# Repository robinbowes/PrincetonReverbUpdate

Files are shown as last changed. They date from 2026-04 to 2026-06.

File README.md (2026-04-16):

# Yet another modded Princeton Reverb

I started off with a Modulus Amplification Princetown Reverb kit. That should have been it. But I wanted to do some of the mods people do, as well as incorporate some of the things Merlin Blencowe suggests in his books.

Initially, I thought I could get away with altering the supplied turret board. Alas, that was just taking up too much thinking time. It was far easier to just draw up a PCB.

The current PCB

Things I've done:

- moved the reverb to its own node
- moved the LFO to its own spur
- used an LED to bias the LFO
- added a large stopper to the PI grid
- reduced the PI coupling caps going to the 6V6s (I could reduce further, but we'll see)
- adopted a multi-star grounding scheme using ground planes for each node, that daisy chain from the reservoir cap to the input
- a single earth <-> signal ground connection near the input
- tried to make the off-board connections short
- it's all on one board! No need for a bias board.

## Things that could do with improving

Should anyone want to take this and make it better, I'd add another mounting hole somewhere in the middle. 

## Licence

This project is licensed under **Creative Commons Attribution-NonCommercial-ShareAlike 4.0 International (CC BY-NC-SA 4.0)**.

© 2026 Tristan Collins

### You are free to:
- **Use and study** the design for personal, educational, or research purposes
- **Adapt** — remix, modify, or build upon it
- **Share** — redistribute in any medium or format

### Under these conditions:
- **Attribution** — credit the original, link to the licence, note any changes
- **NonCommercial** — may not be used for commercial purposes without permission
- **ShareAlike** — adaptations must be released under the same licence

### Commercial use
If you want to manufacture or sell PCBs, kits, or assemblies based on this design, you need a commercial licence. Get in touch: **hard.zoo4108@fastmail.com**



Full licence text: [LICENSE](./LICENSE)

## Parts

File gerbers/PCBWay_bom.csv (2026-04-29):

Designator | Quantity | Value | Footprint | Package | MPN | DNP | Mount_Type | Description | Sim.Device | Sim.Pins | Sim.Pin
C1, C12, C2, C24, C29, C7, C9 | 7 | 22u 50V | CP_Radial_D5.0mm_P2.00mm |  |  |  | tht | [C7,C9]Unpolarized capacitor; [C24,C29]Polarized capacitor
C10 | 1 | 10p 500V | C_Disc_D10.5mm_W5.0mm_P7.50mm_TC |  |  |  | tht | Unpolarized capacitor
C11 | 1 | 3.3n 630V | C_Rect_L16.5mm_W6.0mm_P15.00mm_MKT_TC |  |  |  | tht | Unpolarized capacitor
C13 | 1 | 10n 630V | C_Rect_L11.0mm_W5.1mm_P10.00mm_MKT_TC |  |  |  | tht | Unpolarized capacitor
C14, C19, C8 | 3 | 22n 630V | C_Axial_L17.0mm_D6.5mm_P20.00mm_Horizontal_TC |  |  |  | tht | Unpolarized capacitor
C15, C17 | 2 | 22n 630V | C_Rect_L11.0mm_W5.1mm_P10.00mm_MKT_TC |  |  |  | tht | Unpolarized capacitor
C18, C23, C25 | 3 | 22u 450V | CP_Radial_D12.5mm_P5.00mm |  |  |  | tht | Polarized capacitor
C20, C21 | 2 | 47n 630V | C_Axial_L19.0mm_D7.5mm_P25.00mm_Horizontal_TC |  |  |  | tht | Unpolarized capacitor
C22, C4 | 2 | 100n 630V | C_Axial_L22.0mm_D10.5mm_P27.50mm_Horizontal_TC |  |  |  | tht | Unpolarized capacitor
C27 | 1 | 100p | C_Disc_D10.5mm_W5.0mm_P7.50mm_TC |  |  |  | tht | Unpolarized capacitor
C3 | 1 | 250p 500V | C_Disc_D10.5mm_W5.0mm_P7.50mm_TC |  |  |  | tht | Unpolarized capacitor
C5 | 1 | 47n 630V | C_Axial_L17.0mm_D6.5mm_P20.00mm_Horizontal_TC |  |  |  | tht | Unpolarized capacitor
C6 | 1 | 470p 500V | C_Disc_D7.5mm_W5.0mm_P7.50mm_TC |  |  |  | tht | Unpolarized capacitor
D1 | 1 | UF4007 | D_DO-41_SOD81_P7.62mm_Horizontal |  |  |  | tht | Diode | D | 1=K 2=A
D2 | 1 | Red | LED_D5.0mm |  |  |  | tht | Light emitting diode, small symbol |  |  | 1=K 2=A
R10 | 1 | 6.8k | R_Axial_DIN0414_L11.9mm_D4.5mm_P15.24mm_Horizontal_TC |  |  |  | tht | Resistor
R11, R14, R18, R4, R5 | 5 | 1.5k | R_Axial_DIN0414_L11.9mm_D4.5mm_P15.24mm_Horizontal_TC |  |  |  | tht | Resistor
R12, R29, R33, R34 | 4 | 220k | R_Axial_DIN0414_L11.9mm_D4.5mm_P15.24mm_Horizontal_TC |  |  |  | tht | Resistor
R13, R16, R20, R39, R7, R8 | 6 | 100k | R_Axial_DIN0414_L11.9mm_D4.5mm_P15.24mm_Horizontal_TC |  |  |  | tht | Resistor
R15 | 1 | 3.3M | R_Axial_DIN0414_L11.9mm_D4.5mm_P15.24mm_Horizontal_TC |  |  |  | tht | Resistor
R17 | 1 | 470k | R_Axial_DIN0414_L11.9mm_D4.5mm_P15.24mm_Horizontal_TC |  |  |  | tht | Resistor
R19 | 1 | 47r | R_Axial_DIN0414_L11.9mm_D4.5mm_P15.24mm_Horizontal_TC |  |  |  | tht | Resistor
R21, R23, R24, R31, R6 | 5 | 1Meg | R_Axial_DIN0414_L11.9mm_D4.5mm_P15.24mm_Horizontal_TC |  |  |  | tht | Resistor
R22 | 1 | 2.7k | R_Axial_DIN0414_L11.9mm_D4.5mm_P15.24mm_Horizontal_TC |  |  |  | tht | Resistor
R26 | 1 | 1k | R_Axial_DIN0414_L11.9mm_D4.5mm_P15.24mm_Horizontal_TC |  |  |  | tht | Resistor
R27, R30 | 2 | 56k | R_Axial_DIN0414_L11.9mm_D4.5mm_P15.24mm_Horizontal_TC |  |  |  | tht | Resistor
R28 | 1 | 10k 1W | R_Axial_DIN0617_L17.0mm_D6.0mm_P20.32mm_Horizontal_TC |  |  |  | tht | Resistor
R35 | 1 | 10k | R_Axial_DIN0414_L11.9mm_D4.5mm_P15.24mm_Horizontal_TC |  |  |  | tht | Resistor
R37 | 1 | 100k 1W | R_Axial_DIN0414_L11.9mm_D4.5mm_P15.24mm_Horizontal_TC |  |  |  | tht | Resistor
R40, R41, R9 | 3 | 10k 3W | R_Axial_DIN0617_L17.0mm_D6.0mm_P20.32mm_Horizontal_TC |  |  |  | tht | Resistor
R42 | 1 | 1k 3W | R_Axial_DIN0617_L17.0mm_D6.0mm_P20.32mm_Horizontal_TC |  |  |  | tht | Resistor
R46 | 1 | 220k 3W | R_Axial_DIN0617_L17.0mm_D6.0mm_P20.32mm_Horizontal_TC |  |  |  | tht | Resistor
R48 | 1 | 1r 1% | R_Axial_DIN0414_L11.9mm_D4.5mm_P15.24mm_Horizontal_TC |  |  |  | tht | Resistor
RV7 | 1 | 22k Lin | Potentiometer_Bourns_3296W_Vertical |  |  |  | tht | Potentiometer
TP1 | 1 | BiasTP | TestPoint_Keystone_5005-5009_Compact |  |  |  | tht | test point
TP2 | 1 | GND | TestPoint_Keystone_5005-5009_Compact |  |  |  | tht | test point

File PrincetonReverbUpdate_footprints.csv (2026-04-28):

Reference | Qty | Value | Footprint
C1,C2,C7,C9,C12,C24,C29 | 7 | 22u 50V | Capacitor_THT:CP_Radial_D5.0mm_P2.00mm
R7,R8,R13,R16,R20,R39 | 6 | 100k | Library:R_Axial_DIN0414_L11.9mm_D4.5mm_P15.24mm_Horizontal_TC
R6,R21,R23,R24,R31 | 5 | 1Meg | Library:R_Axial_DIN0414_L11.9mm_D4.5mm_P15.24mm_Horizontal_TC
R4,R5,R11,R14,R18 | 5 | 1.5k | Library:R_Axial_DIN0414_L11.9mm_D4.5mm_P15.24mm_Horizontal_TC
R12,R29,R33,R34 | 4 | 220k | Library:R_Axial_DIN0414_L11.9mm_D4.5mm_P15.24mm_Horizontal_TC
R9,R40,R41 | 3 | 10k 3W | Library:R_Axial_DIN0617_L17.0mm_D6.0mm_P20.32mm_Horizontal_TC
D3,D4,D5 | 3 | UF4007
C18,C23,C25 | 3 | 22u 450V | Capacitor_THT:CP_Radial_D12.5mm_P5.00mm
C8,C14,C19 | 3 | 22n 630V | Library:C_Axial_L17.0mm_D6.5mm_P20.00mm_Horizontal_TC
RV1,RV5 | 2 | 250k Log
R36,R38 | 2 | 470r 3W
R27,R30 | 2 | 56k | Library:R_Axial_DIN0414_L11.9mm_D4.5mm_P15.24mm_Horizontal_TC
R25,R32 | 2 | 1.5k
C20,C21 | 2 | 47n 630V | Library:C_Axial_L19.0mm_D7.5mm_P25.00mm_Horizontal_TC
C15,C17 | 2 | 22n 630V | Library:C_Rect_L11.0mm_W5.1mm_P10.00mm_MKT_TC
C4,C22 | 2 | 100n 630V | Library:C_Axial_L22.0mm_D10.5mm_P27.50mm_Horizontal_TC
TP2 | 1 | GND | TestPoint:TestPoint_Keystone_5005-5009_Compact
TP1 | 1 | BiasTP | TestPoint:TestPoint_Keystone_5005-5009_Compact
RV7 | 1 | 22k Lin | Potentiometer_THT:Potentiometer_Bourns_3296W_Vertical
RV6 | 1 | 3M RLog
RV4 | 1 | 250k Lin
RV3 | 1 | 100k Log
RV2 | 1 | 1M Log
R48 | 1 | 1r 1% | Library:R_Axial_DIN0414_L11.9mm_D4.5mm_P15.24mm_Horizontal_TC
R46 | 1 | 220k 3W | Library:R_Axial_DIN0617_L17.0mm_D6.0mm_P20.32mm_Horizontal_TC
R45 | 1 | 470k
R44 | 1 | 680r 5W
R43 | 1 | 1k 3W
R42 | 1 | 1k 3W | Library:R_Axial_DIN0617_L17.0mm_D6.0mm_P20.32mm_Horizontal_TC
R37 | 1 | 100k 1W | Library:R_Axial_DIN0414_L11.9mm_D4.5mm_P15.24mm_Horizontal_TC
R35 | 1 | 10k | Library:R_Axial_DIN0414_L11.9mm_D4.5mm_P15.24mm_Horizontal_TC
R28 | 1 | 10k 1W | Library:R_Axial_DIN0617_L17.0mm_D6.0mm_P20.32mm_Horizontal_TC
R26 | 1 | 1k | Library:R_Axial_DIN0414_L11.9mm_D4.5mm_P15.24mm_Horizontal_TC
R22 | 1 | 2.7k | Library:R_Axial_DIN0414_L11.9mm_D4.5mm_P15.24mm_Horizontal_TC
R19 | 1 | 47r | Library:R_Axial_DIN0414_L11.9mm_D4.5mm_P15.24mm_Horizontal_TC
R17 | 1 | 470k | Library:R_Axial_DIN0414_L11.9mm_D4.5mm_P15.24mm_Horizontal_TC
R15 | 1 | 3.3M | Library:R_Axial_DIN0414_L11.9mm_D4.5mm_P15.24mm_Horizontal_TC
R10 | 1 | 6.8k | Library:R_Axial_DIN0414_L11.9mm_D4.5mm_P15.24mm_Horizontal_TC
R3 | 1 | 1Meg
R2 | 1 | 10k
D2 | 1 | Red | LED_THT:LED_D5.0mm
D1 | 1 | UF4007 | Diode_THT:D_DO-41_SOD81_P7.62mm_Horizontal
CN1 | 1 | JJ CanCap
C27 | 1 | 100p | Library:C_Disc_D10.5mm_W5.0mm_P7.50mm_TC
C16 | 1 | 100p 2kV
C13 | 1 | 10n 630V | Library:C_Rect_L11.0mm_W5.1mm_P10.00mm_MKT_TC
C11 | 1 | 3.3n 630V | Library:C_Rect_L16.5mm_W6.0mm_P15.00mm_MKT_TC
C10 | 1 | 10p 500V | Library:C_Disc_D10.5mm_W5.0mm_P7.50mm_TC
C6 | 1 | 470p 500V | Library:C_Disc_D7.5mm_W5.0mm_P7.50mm_TC
C5 | 1 | 47n 630V | Library:C_Axial_L17.0mm_D6.5mm_P20.00mm_Horizontal_TC
C3 | 1 | 250p 500V | Library:C_Disc_D10.5mm_W5.0mm_P7.50mm_TC

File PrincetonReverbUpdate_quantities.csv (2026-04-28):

Reference | Qty | Value
R4,R5,R11,R14,R18,R25,R32 | 7 | 1.5k
C1,C2,C7,C9,C12,C24,C29 | 7 | 22u 50V
R7,R8,R13,R16,R20,R39 | 6 | 100k
R3,R6,R21,R23,R24,R31 | 6 | 1Meg
C8,C14,C15,C17,C19 | 5 | 22n 630V
R12,R29,R33,R34 | 4 | 220k
D1,D3,D4,D5 | 4 | UF4007
R9,R40,R41 | 3 | 10k 3W
C18,C23,C25 | 3 | 22u 450V
C5,C20,C21 | 3 | 47n 630V
RV1,RV5 | 2 | 250k Log
R42,R43 | 2 | 1k 3W
R36,R38 | 2 | 470r 3W
R27,R30 | 2 | 56k
R17,R45 | 2 | 470k
R2,R35 | 2 | 10k
C4,C22 | 2 | 100n 630V
TP2 | 1 | GND
TP1 | 1 | BiasTP
RV7 | 1 | 22k Lin
RV6 | 1 | 3M RLog
RV4 | 1 | 250k Lin
RV3 | 1 | 100k Log
RV2 | 1 | 1M Log
R48 | 1 | 1r 1%
R46 | 1 | 220k 3W
R44 | 1 | 680r 5W
R37 | 1 | 100k 1W
R28 | 1 | 10k 1W
R26 | 1 | 1k
R22 | 1 | 2.7k
R19 | 1 | 47r
R15 | 1 | 3.3M
R10 | 1 | 6.8k
D2 | 1 | Red
CN1 | 1 | JJ CanCap
C27 | 1 | 100p
C16 | 1 | 100p 2kV
C13 | 1 | 10n 630V
C11 | 1 | 3.3n 630V
C10 | 1 | 10p 500V
C6 | 1 | 470p 500V
C3 | 1 | 250p 500V

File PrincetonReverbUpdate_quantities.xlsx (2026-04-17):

Reference | Qty | Value | Actual in hand | Notes
R4,R5,R11,R14,R18,R25,R32 | 7 | 1.5k | 8 | 2 of the 7 are 6V6 grid stoppers
C1,C2,C7,C9,C12,C24,C29 | 7 | 22u 50V
R7,R8,R13,R16,R20,R39 | 6 | 100k | 7
R3,R6,R21,R23,R24,R31 | 6 | 1Meg | 6
C8,C14,C15,C17,C19 | 5 | 22n 630V
R12,R29,R33,R34 | 4 | 220k | 4
R9,R40,R41 | 3 | 10k 3W | 4
D1,D3,D4 | 3 | UF4007
C18,C23,C25 | 3 | 22u 450V
C5,C20,C21 | 3 | 47n 630V
RV1,RV5 | 2 | 250k Log
R36,R38 | 2 | 470r 3W | 3
R27,R30 | 2 | 56k | 2
R26 | 1 | 1k | 1
R17,R45 | 2 | 470k | 2
R2,R35 | 2 | 10k | 3
C4,C22 | 2 | 100n 630V
TP2 | 1 | GND
TP1 | 1 | BiasTP
RV7 | 1 | 22k Lin
RV6 | 1 | 3M RLog
RV4 | 1 | 250k Lin
RV3 | 1 | 100k Log
RV2 | 1 | 1M Log
R48 | 1 | 1r 1% | 1
R46 | 1 | 220k 3W | 1
R44 | 1 | 680r 5W | 1
R42,R43 | 2 | 1k 3W | 3
R37 | 1 | 100k 1W | 2
R28 | 1 | 10k 1W | 1 | use 3W?
R22 | 1 | 2.7k | 1
R19 | 1 | 47r | 2
R15 | 1 | 3.3M | 1
R10 | 1 | 6.8k | 2
D2 | 1 | Red
CN1 | 1 | JJ CanCap
C27 | 1 | 100-470p
C16 | 1 | 100p 2kV
C13 | 1 | 10n 630V
C11 | 1 | 3.3n 630V
C10 | 1 | 10p 500V
C6 | 1 | 470p 500V
C3 | 1 | 250p 500V

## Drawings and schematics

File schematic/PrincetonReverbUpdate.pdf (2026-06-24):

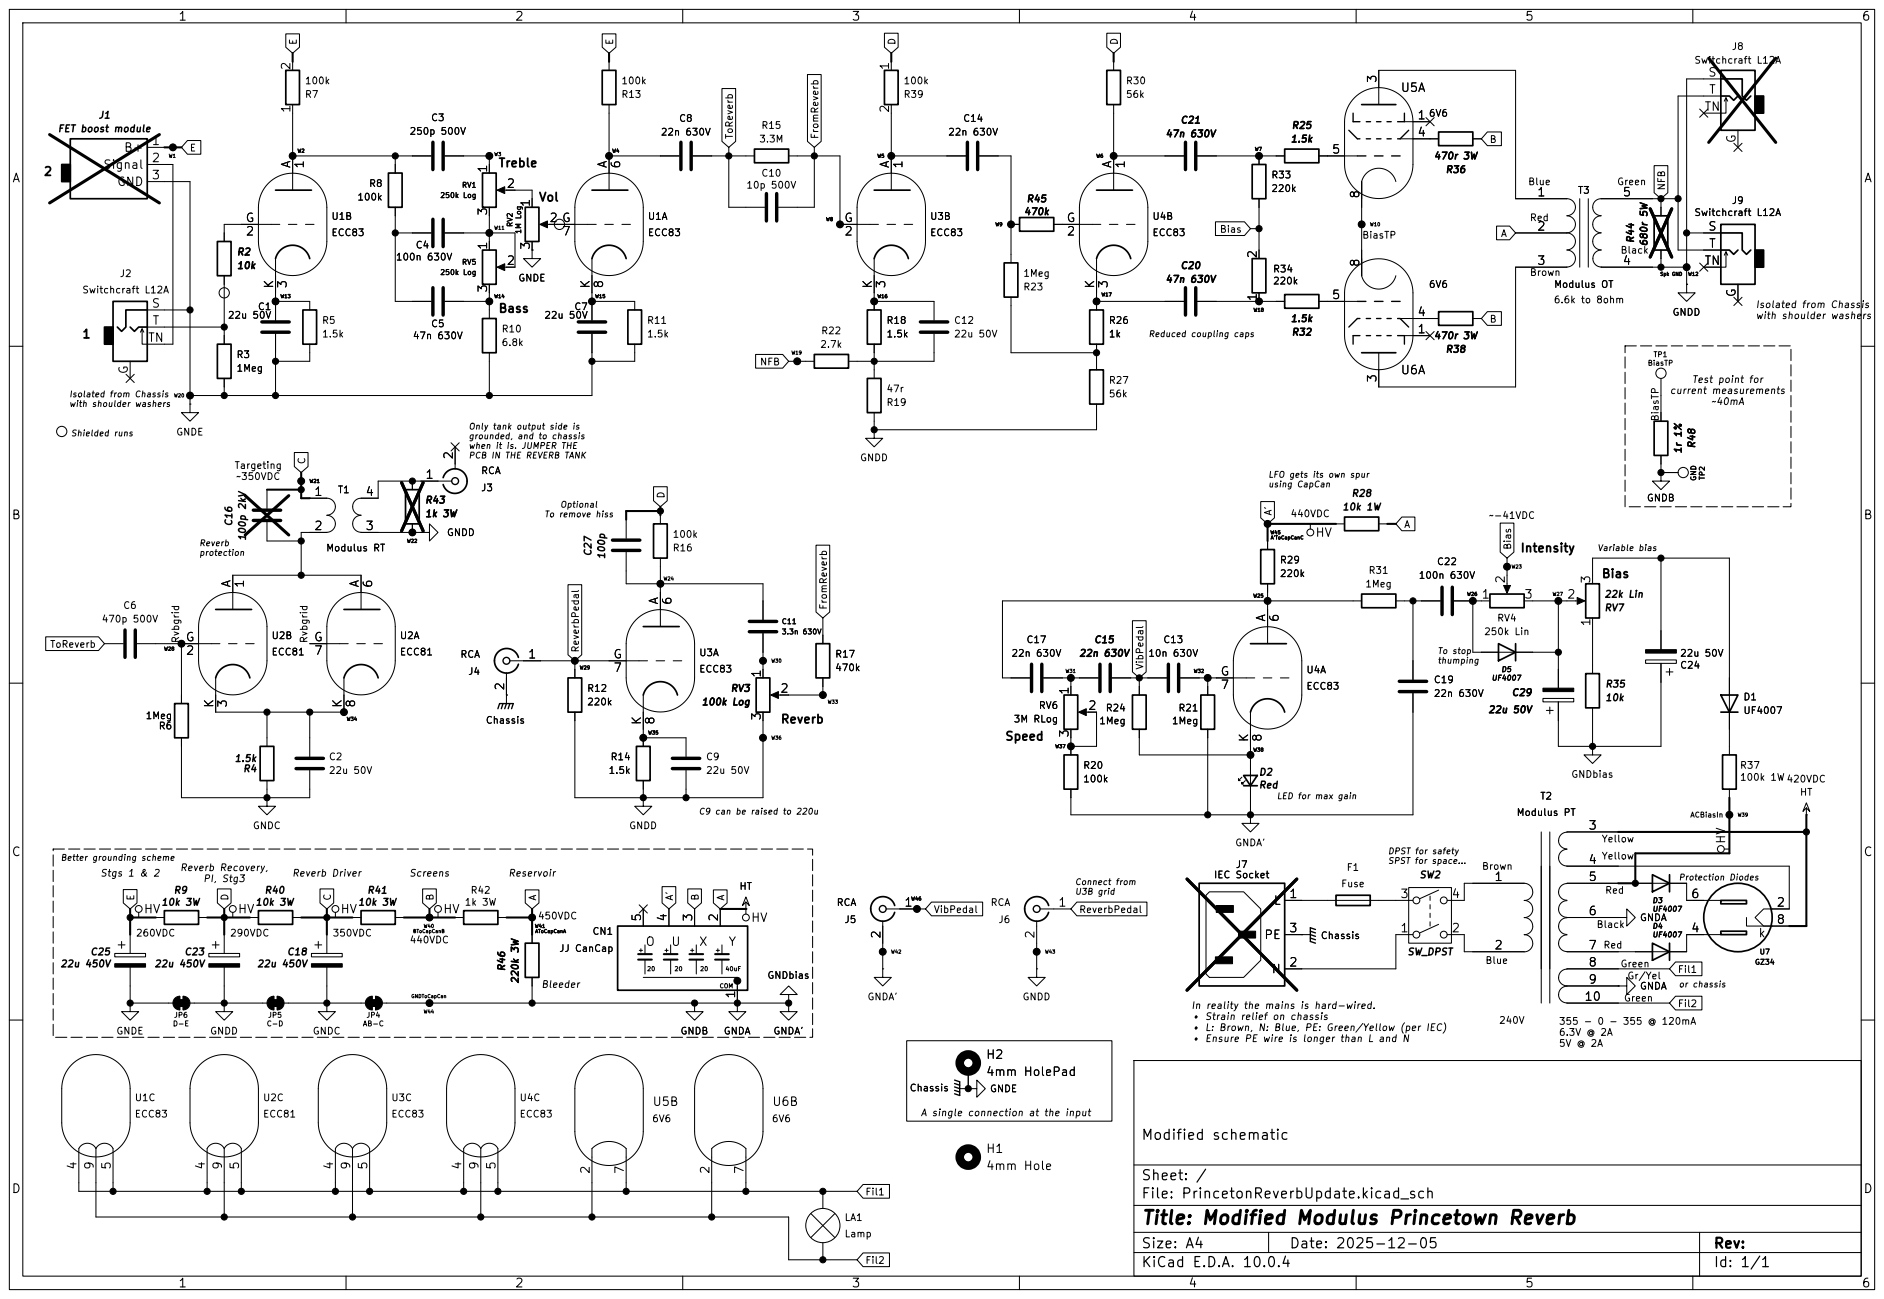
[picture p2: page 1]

Variable bias Green Brown

Isolated from Chassis with shoulder washers 440VDC

TN

Test point for current measurements

Green Red Black Yellow Reverb

LED for max gain

Reverb Recovery, PI, Stg3 Stgs 1 & 2

In reality the mains is hard-wired. • Strain relief on chassis • L: Brown, N: Blue, PE: Green/Yellow (per IEC) • Ensure PE wire is longer than L and N

Sheet: /
File: PrincetonReverbUpdate.kicad_sch
Title: Modified Modulus Princetown Reverb

Size: A4 | Rev:
KiCad E.D.A. 10.0.4 | Id: 1/1

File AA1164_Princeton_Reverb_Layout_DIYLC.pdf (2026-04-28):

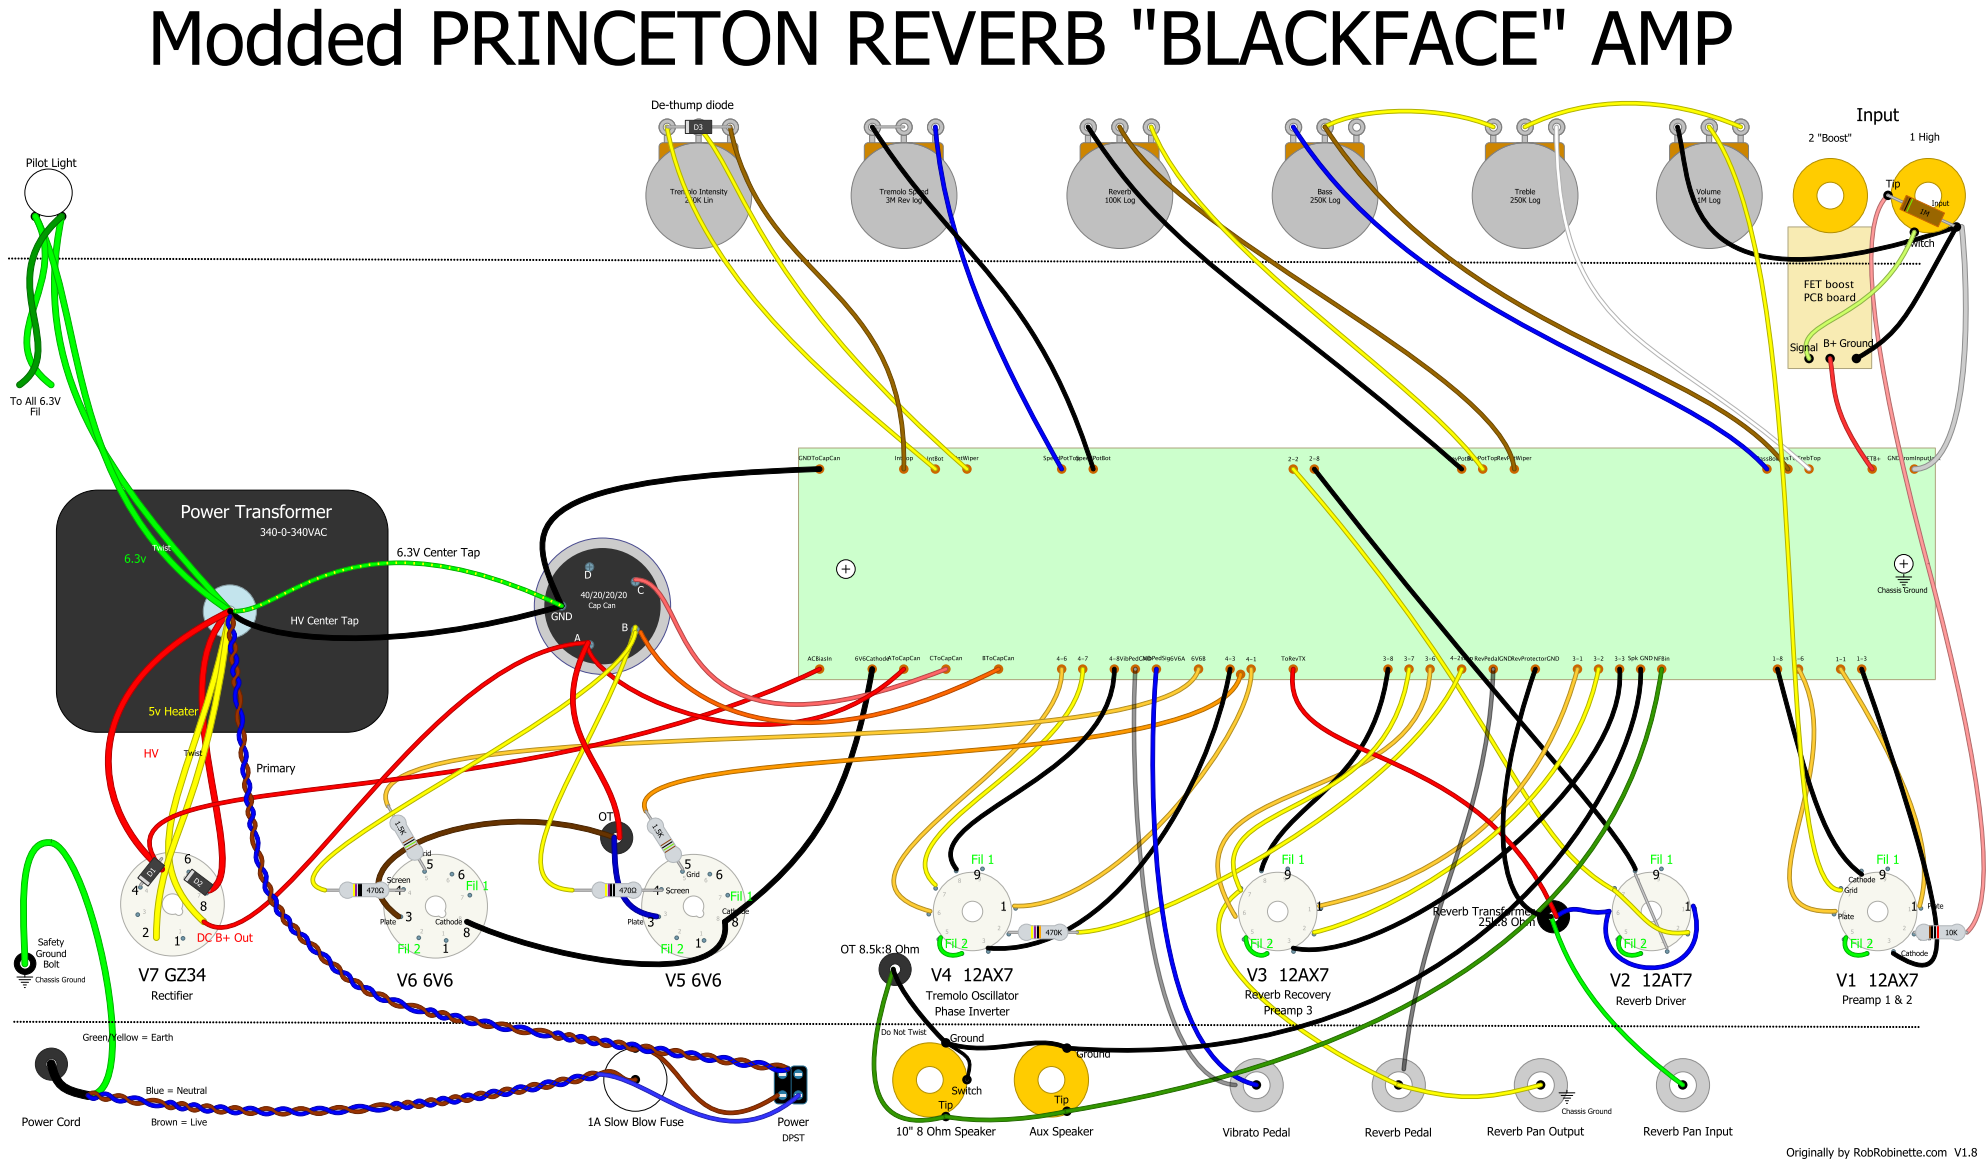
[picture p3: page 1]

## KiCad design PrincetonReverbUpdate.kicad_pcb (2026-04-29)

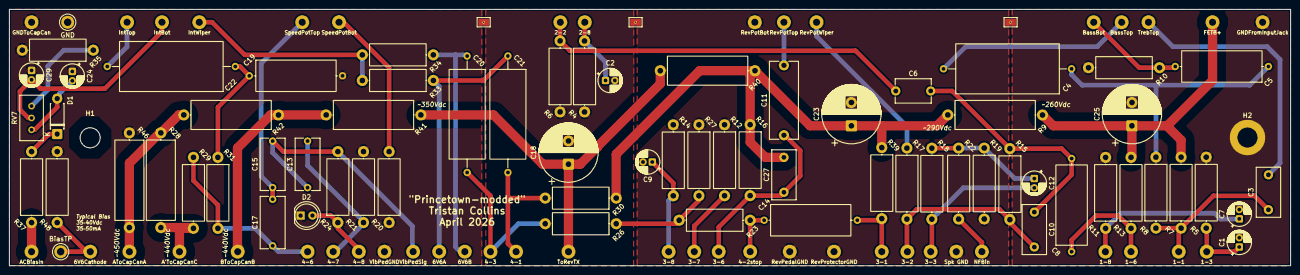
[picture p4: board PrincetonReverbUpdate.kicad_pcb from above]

Board: 2 copper layers, 275.0 x 55.0 mm, 119 parts (0 on the bottom side), 52 nets.

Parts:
C1, C2, C7, C9, C12, C24, C29: 22u 50V; CP_Radial_D5.0mm_P2.00mm
C3: 250p 500V; C_Disc_D10.5mm_W5.0mm_P7.50mm_TC
C4, C22: 100n 630V; C_Axial_L22.0mm_D10.5mm_P27.50mm_Horizontal_TC
C5: 47n 630V; C_Axial_L17.0mm_D6.5mm_P20.00mm_Horizontal_TC
C6: 470p 500V; C_Disc_D7.5mm_W5.0mm_P7.50mm_TC
C8, C14, C19: 22n 630V; C_Axial_L17.0mm_D6.5mm_P20.00mm_Horizontal_TC
C10: 10p 500V; C_Disc_D10.5mm_W5.0mm_P7.50mm_TC
C11: 3.3n 630V; C_Rect_L16.5mm_W6.0mm_P15.00mm_MKT_TC
C13: 10n 630V; C_Rect_L11.0mm_W5.1mm_P10.00mm_MKT_TC
C15, C17: 22n 630V; C_Rect_L11.0mm_W5.1mm_P10.00mm_MKT_TC
C18, C23, C25: 22u 450V; CP_Radial_D12.5mm_P5.00mm
C20, C21: 47n 630V; C_Axial_L19.0mm_D7.5mm_P25.00mm_Horizontal_TC
C27: 100p; C_Disc_D10.5mm_W5.0mm_P7.50mm_TC
D1: UF4007; D_DO-41_SOD81_P7.62mm_Horizontal
D2: Red; LED_D5.0mm
H1: 4mm Hole; MountingHole_4.3mm_M4_TC
H2: 4mm HolePad; MountingHole_4.3mm_M4_ISO7380_Pad
JP4: AB-C; SolderJumper-2_P1_3mm_Bridged_Pad1_0x1_5mm_TC_Via
JP5: C-D; SolderJumper-2_P1_3mm_Bridged_Pad1_0x1_5mm_TC_Via
JP6: D-E; SolderJumper-2_P1_3mm_Bridged_Pad1_0x1_5mm_TC_Via
R4, R5, R11, R14, R18: 1.5k; R_Axial_DIN0414_L11.9mm_D4.5mm_P15.24mm_Horizontal_TC
R6, R21, R23, R24, R31: 1Meg; R_Axial_DIN0414_L11.9mm_D4.5mm_P15.24mm_Horizontal_TC
R7, R8, R13, R16, R20, R39: 100k; R_Axial_DIN0414_L11.9mm_D4.5mm_P15.24mm_Horizontal_TC
R9, R40, R41: 10k 3W; R_Axial_DIN0617_L17.0mm_D6.0mm_P20.32mm_Horizontal_TC
R10: 6.8k; R_Axial_DIN0414_L11.9mm_D4.5mm_P15.24mm_Horizontal_TC
R12, R29, R33, R34: 220k; R_Axial_DIN0414_L11.9mm_D4.5mm_P15.24mm_Horizontal_TC
R15: 3.3M; R_Axial_DIN0414_L11.9mm_D4.5mm_P15.24mm_Horizontal_TC
R17: 470k; R_Axial_DIN0414_L11.9mm_D4.5mm_P15.24mm_Horizontal_TC
R19: 47r; R_Axial_DIN0414_L11.9mm_D4.5mm_P15.24mm_Horizontal_TC
R22: 2.7k; R_Axial_DIN0414_L11.9mm_D4.5mm_P15.24mm_Horizontal_TC
R26: 1k; R_Axial_DIN0414_L11.9mm_D4.5mm_P15.24mm_Horizontal_TC
R27, R30: 56k; R_Axial_DIN0414_L11.9mm_D4.5mm_P15.24mm_Horizontal_TC
R28: 10k 1W; R_Axial_DIN0617_L17.0mm_D6.0mm_P20.32mm_Horizontal_TC
R35: 10k; R_Axial_DIN0414_L11.9mm_D4.5mm_P15.24mm_Horizontal_TC
R37: 100k 1W; R_Axial_DIN0414_L11.9mm_D4.5mm_P15.24mm_Horizontal_TC
R42: 1k 3W; R_Axial_DIN0617_L17.0mm_D6.0mm_P20.32mm_Horizontal_TC
R46: 220k 3W; R_Axial_DIN0617_L17.0mm_D6.0mm_P20.32mm_Horizontal_TC
R48: 1r 1%; R_Axial_DIN0414_L11.9mm_D4.5mm_P15.24mm_Horizontal_TC
RV7: 22k Lin; Potentiometer_Bourns_3296W_Vertical
TP1: BiasTP; TestPoint_Keystone_5005-5009_Compact
TP2: GND; TestPoint_Keystone_5005-5009_Compact
W1: FETB+; SolderWire_TC
W2: 1-1; SolderWire_TC
W3: TrebTop; SolderWire_TC
W4: 1-6; SolderWire_TC
W5: 3-1; SolderWire_TC
W6: 4-1; SolderWire_TC
W7: 6V6A; SolderWire_TC
W8: 3-2; SolderWire_TC
W9: 4-2stop; SolderWire_TC
W10: 6V6Cathode; SolderWire_TC
W11: BassTop; SolderWire_TC
W12: Spk GND; SolderWire_TC
W13: 1-3; SolderWire_TC
W14: BassBot; SolderWire_TC
W15: 1-8; SolderWire_TC
W16: 3-3; SolderWire_TC
W17: 4-3; SolderWire_TC
W18: 6V6B; SolderWire_TC
W19: NFBin; SolderWire_TC
W20: GNDFromInputJack; SolderWire_TC
W21: ToRevTX; SolderWire_TC
W22: RevProtectorGND; SolderWire_TC
W23: IntWiper; SolderWire_TC
W24: 3-6; SolderWire_TC
W25: 4-6; SolderWire_TC
W26: IntTop; SolderWire_TC
W27: IntBot; SolderWire_TC
W28: 2-2; SolderWire_TC
W29: 3-7; SolderWire_TC
W30: RevPotTop; SolderWire_TC
W31: SpeedPotTop; SolderWire_TC
W32: 4-7; SolderWire_TC
W33: RevPotWiper; SolderWire_TC
W34: 2-8; SolderWire_TC
W35: 3-8; SolderWire_TC
W36: RevPotBot; SolderWire_TC
W37: SpeedPotBot; SolderWire_TC
W38: 4-8; SolderWire_TC
W39: ACBiasIn; SolderWire_TC
W40: BToCapCanB; SolderWire_TC
W41: AToCapCanA; SolderWire_TC
W42: VibPedGND; SolderWire_TC
W43: RevPedalGND; SolderWire_TC
W44: GNDToCapCan; SolderWire_TC
W45: A'ToCapCanC; SolderWire_TC
W46: VibPedSig; SolderWire_TC

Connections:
/BiasTP: R48.1, TP1.1 (1_1), W10.1 (1_1)
/Rvbgrid: C6.1, R6.2, W28.1 (1_1)
A: R28.1, R42.2, R46.2, W41.1 (1_1)
A': R28.2, R29.2, W45.1 (1_1)
B: R41.2, R42.1, W40.1 (1_1)
Bias: R33.2, R34.2, W23.1 (1_1)
C: C18.1, R40.2, R41.1, W21.1 (1_1)
Chassis: C1.2, C7.2, C25.2, H2.1 (1_1), JP6.2 (B), R5.2, R10.2, R11.2, W20.1 (1_1)
D: C23.1, C27.2, R9.2, R16.1, R30.1, R39.1, R40.1
E: C25.1, R7.2, R9.1, R13.2, W1.1 (1_1)
FromReverb: C10.2, R15.2, R17.2, W8.1 (1_1)
GNDA: C19.2, C24.1, C29.1, D2.1 (K), JP4.1 (A), R20.1, R21.2, R35.2, R46.1, R48.2, TP2.1 (1_1), W42.1 (1_1), W44.1 (1_1)
GNDC: C2.2, C18.2, JP4.2 (B), JP5.1 (A), R4.1, R6.1
GNDD: C9.2, C23.2, JP5.2 (B), JP6.1 (A), R12.1, R14.1, R19.2, R27.1, W12.1 (1_1), W22.1 (1_1), W36.1 (1_1), W43.1 (1_1)
NFB: R22.2, W19.1 (1_1)
unnamed: C1.1, R5.1, W13.1 (1_1)
unnamed: C2.1, R4.2, W34.1 (1_1)
unnamed: C3.1, R7.1, R8.1, W2.1 (1_1)
unnamed: C3.2, W3.1 (1_1)
unnamed: C4.1, C5.1, R8.2
unnamed: C4.2, W11.1 (1_1)
unnamed: C5.2, R10.1, W14.1 (1_1)
unnamed: C7.1, R11.1, W15.1 (1_1)
unnamed: C8.1, R13.1, W4.1 (1_1)
unnamed: C9.1, R14.2, W35.1 (1_1)
unnamed: C11.1, C27.1, R16.2, W24.1 (1_1)
unnamed: C11.2, W30.1 (1_1)
unnamed: C12.1, R18.1, R19.1, R22.1
unnamed: C12.2, R18.2, W16.1 (1_1)
unnamed: C13.2, R21.1, W32.1 (1_1)
unnamed: C14.1, R23.1, W9.1 (1_1)
unnamed: C14.2, R39.2, W5.1 (1_1)
unnamed: C15.1, C17.2, W31.1 (1_1)
unnamed: C17.1, R29.1, R31.2, W25.1 (1_1)
unnamed: C19.1, C22.1, R31.1
unnamed: C20.1, R34.1, W18.1 (1_1)
unnamed: C20.2, R26.2, W17.1 (1_1)
unnamed: C21.1, R33.1, W7.1 (1_1)
unnamed: C21.2, R30.2, W6.1 (1_1)
unnamed: C22.2, W26.1 (1_1)
unnamed: C29.2, RV7.2, W27.1 (1_1)
unnamed: C24.2, D1.2 (A), RV7.3
unnamed: D1.1 (K), R37.2
unnamed: D2.2 (A), R24.1, W38.1 (1_1)
unnamed: R17.1, W33.1 (1_1)
unnamed: R20.2, W37.1 (1_1)
unnamed: R23.2, R26.1, R27.2
unnamed: R35.1, RV7.1
unnamed: R37.1, W39.1 (1_1)
ReverbPedal: R12.2, W29.1 (1_1)
ToReverb: C6.2, C8.2, C10.1, R15.1
VibPedal: C13.1, C15.2, R24.2, W46.1 (1_1)

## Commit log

2026-02-16 remove balance control
    [PrincetonReverbUpdate.kicad_sch]
2026-02-16 Update schematic PDF [skip ci]
2026-04-03 bump mods branch to kiCad 10
    [PrincetonReverbUpdate.kicad_sch]
2026-04-03 adding Wx symbols for off-board wiring
    [PrincetonReverbUpdate.kicad_pcb, PrincetonReverbUpdate.kicad_sch]
2026-04-03 refine schematic
    [PrincetonReverbUpdate.kicad_pcb, PrincetonReverbUpdate.kicad_sch]
2026-04-03 initial footprint assignment
    [PrincetonReverbUpdate.kicad_pcb, PrincetonReverbUpdate.kicad_sch]
2026-04-03 Add mods-pcb branch to workflow triggers
2026-04-03 Update workflow to generate PCB render and PDF
2026-04-03 Update KiCad actions to version 2.0
2026-04-03 Change PCB output to use image instead of render
    Updated PCB output configuration in kicad-pdf workflow.
2026-04-03 Update schematic PDF and PCB render [skip ci]
2026-04-03 Increasing pcb image quality
2026-04-04 more layout
    [PrincetonReverbUpdate.kicad_pcb, PrincetonReverbUpdate.kicad_sch]
2026-04-04 layout changes
    [PrincetonReverbUpdate.kicad_pcb, PrincetonReverbUpdate.kicad_sch]
2026-04-05 more error fixing
    [PrincetonReverbUpdate.kicad_pcb, PrincetonReverbUpdate.kicad_sch]
2026-04-06 layout, scheme tweak, addlayout image examples
    [PrincetonReverbUpdate.kicad_pcb, PrincetonReverbUpdate.kicad_sch]
2026-04-08 major layout changes and scheme tweaks
    [PrincetonReverbUpdate.kicad_pcb, PrincetonReverbUpdate.kicad_sch]
2026-04-08 hide pin numbers
    [PrincetonReverbUpdate.kicad_sch]
2026-04-09 simplify scheme, tweak footprints
    [PrincetonReverbUpdate.kicad_pcb, PrincetonReverbUpdate.kicad_sch]
2026-04-09 more layout and footprint alterations
    [PrincetonReverbUpdate.kicad_pcb, PrincetonReverbUpdate.kicad_sch]
2026-04-09 fix scheme error
    [PrincetonReverbUpdate.kicad_sch]
2026-04-10 more layout iterations
    [PrincetonReverbUpdate.kicad_pcb, PrincetonReverbUpdate.kicad_sch]
2026-04-11 place mounting holes
    [PrincetonReverbUpdate.kicad_pcb]
2026-04-11 initial routing attempt, netclasses
    [PrincetonReverbUpdate.kicad_pcb, PrincetonReverbUpdate.kicad_sch]
2026-04-12 more layout, zones, footprints
    [PrincetonReverbUpdate.kicad_pcb, PrincetonReverbUpdate.kicad_sch]
2026-04-12 footprint updates, layout updates
    [PrincetonReverbUpdate.kicad_pcb, PrincetonReverbUpdate.kicad_sch]
2026-04-13 adding DIYLC convertor, and Robinette Layout
    [PrincetonReverbUpdate.kicad_pcb, PrincetonReverbUpdate.kicad_sch]
2026-04-13 Fixes, added DIYLC files
    [PrincetonReverbUpdate.kicad_pcb, PrincetonReverbUpdate.kicad_sch]
2026-04-14 Taking a commit in case I need to revert ahead of trying to sqeeze the board smaller.
    [PrincetonReverbUpdate.kicad_pcb]
2026-04-14 board resizing, improved layouts
    [PrincetonReverbUpdate.kicad_pcb, PrincetonReverbUpdate.kicad_sch]
2026-04-14 rename valve connections
    [PrincetonReverbUpdate.kicad_pcb, PrincetonReverbUpdate.kicad_sch]
2026-04-14 Close to fab
    [PrincetonReverbUpdate.kicad_pcb, PrincetonReverbUpdate.kicad_sch]
2026-04-14 files for fabrication
    [PCBWay_bom.csv, PCBWay_positions.csv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]
2026-04-15 Fix input wiring
    [PrincetonReverbUpdate.kicad_sch]
2026-04-16 fix rectifier, update readme, prep bom
    [PrincetonReverbUpdate.kicad_sch]
2026-04-16 Typo on schematic
    [PrincetonReverbUpdate.kicad_sch]
2026-04-17 add part ratings, tweak values
    [PrincetonReverbUpdate.kicad_sch]
2026-04-17 updating BoM
    [PrincetonReverbUpdate.kicad_sch, PrincetonReverbUpdate_footprints.csv, PrincetonReverbUpdate_quantities.csv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]
2026-04-24 add thump diode, scheme tweaks
    [PrincetonReverbUpdate.kicad_sch, PrincetonReverbUpdate_footprints.csv, PrincetonReverbUpdate_quantities.csv]
2026-04-28 as built
    [PrincetonReverbUpdate.kicad_pcb, PrincetonReverbUpdate.kicad_sch, PrincetonReverbUpdate_footprints.csv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]
2026-04-29 version built
    [PCBWay_bom.csv, PCBWay_positions.csv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]
2026-06-11 add note to schematic on jack grounding
    [PrincetonReverbUpdate.kicad_sch]
2026-06-11 replace Arial -> Default fonts
    [PrincetonReverbUpdate.kicad_sch]

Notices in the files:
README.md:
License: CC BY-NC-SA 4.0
